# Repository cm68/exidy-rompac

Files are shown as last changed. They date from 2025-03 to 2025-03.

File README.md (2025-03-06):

this is a 3d printable exidy rom-pac case, tested with the original rom-pac
and the modern clone at https://github.com/abzman/Exidy-Sorcerer-Stuff

I uploaded it to thingyverse.

install openscad, run make, and print the generated STL files to your
heart's content.

the rompac.stl file is not really useful as anything other than a visual
fit check or thumbnail.

I printed mine on a flashforge guider 2S with PLA, but be fine with anything

PLA at 215 degrees filament, 70 degree platform 
with raft, 25% fill. the pin is a bit weak

PETG at 240, platform 70 with shell thickness = 4mm.  
this has the pin strong enough.

the shells are held together with the press-fit pin, this might want a little
sanding, depending on your printer.  if it is loose, tape works.
i might put locking tabs on the inside surfaces of the front bevel,
if you do this before me, send it to me at curt@zen-room.org.

yeah, it's GPL3.  ship it and derived works with buildable source code; 
if you learned something from this, you must pay that learning forward.

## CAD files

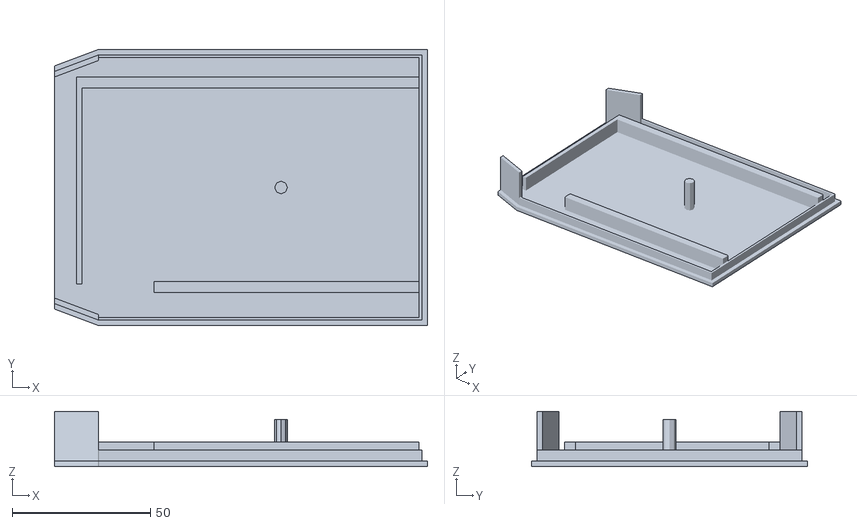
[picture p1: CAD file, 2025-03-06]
rompac-t.stl
135.0 x 100.0 x 20.0

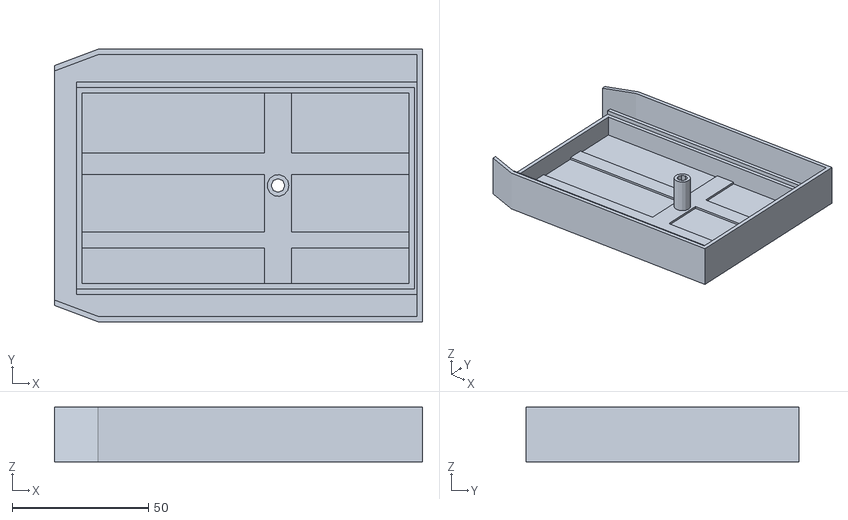
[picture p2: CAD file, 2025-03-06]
rompac-b.stl
135.0 x 100.0 x 20.0

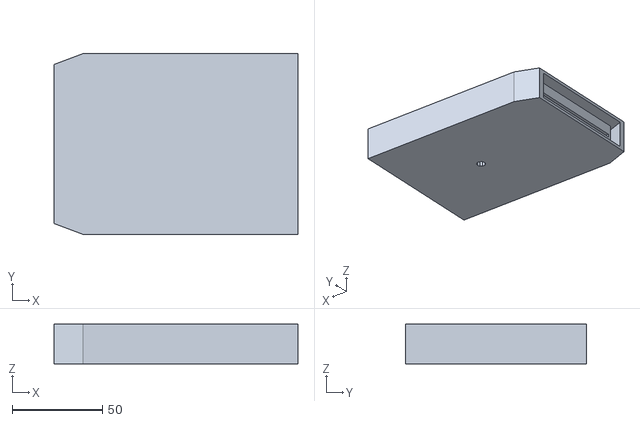
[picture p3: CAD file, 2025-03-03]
rompac.stl
135.0 x 100.0 x 22.0

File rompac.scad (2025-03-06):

/*
 * $Id: rompac.scad 2029 2025-03-02 08:44:02 curt
 */

width = 100;
length = 135;
basethick = 2;
pin = 82;
bevel_width = 6;
bevel_len = 16;
high = 20;
plat = 11;
sidethick = 2;

/* size of pin and hole */
pinouter = 4; // fixed by size of PCB hole
pininner = 2.3;
pinhole = 2.5;
pinlength = high - 3;

// edit this to generate either "b" - bottom
// or "t" - top
// or both -"tb"
express = "tb";

module platform() {
    translate([8,12,0]) cube([2,73,plat]);
    translate([8,12,0]) cube([124,2,plat]);
    translate([8,84,0]) cube([124,2,plat]);
    translate([130,12,0]) cube([2,73,plat]); 
}

module lip() {
    translate([8,10,0]) cube([126,2,plat+2]);
    translate([8,86,0]) cube([126,2,plat+2]);
    translate([132,10,0]) cube([2,78,plat+2]); 
}

module base() {
    difference() {
        linear_extrude(height = basethick) 
            polygon([
                [ 0, bevel_width],
                [ 0, width - bevel_width],
                [ bevel_len, width],
                [ length, width],
                [ length, 0],
                [ bevel_len, 0]]);
        translate([10, 14, 1]) cube([120, 70, 2]);
    }
    translate([0, 54, 0]) cube([length, 8, 2]);
    translate([0, 27, 0]) cube([length, 6, 2]);
    translate([pin - 5, 0, 0]) cube([10, width, 2]);
}

module edge() {
    union() {
        translate([bevel_len, 0, 0]) cube([length - bevel_len, sidethick, high]);
        translate([length - sidethick, 0, 0]) cube([sidethick, width, high]);
        translate([bevel_len, width - sidethick, 0]) cube([length - bevel_len, sidethick, high]);
        linear_extrude(height = high) union() {
            polygon([[0, bevel_width + sidethick], [0, bevel_width], 
                [bevel_len, 0], [bevel_len, sidethick]]);
            polygon([[0, width - bevel_width], [0, width - bevel_width - sidethick], 
                [bevel_len, width - sidethick], [bevel_len, width]]);
        }
    }
}

module top() {
    toplip = 6;
    linear_extrude(height = basethick) 
        polygon([
                [ 0, bevel_width],
                [ 0, width - bevel_width],
                [ bevel_len, width],
                [ length, width],
                [ length, 0],
                [ bevel_len, 0]]);
    
    translate([pin, width / 2, 0]) cylinder(pinlength, r = pininner);

    translate([bevel_len, sidethick, 0]) cube([length - bevel_len - sidethick, 1, toplip]);
    translate([length - sidethick - 1, sidethick, 0]) cube([1, width - (sidethick * 2), toplip]);
    translate([bevel_len, width - sidethick - 1, 0]) cube([length - bevel_len - sidethick, 1, toplip]);
    linear_extrude(height = 20) {
        polygon([[0, bevel_width + (sidethick *2)], [0, bevel_width + sidethick], 
                [bevel_len, sidethick], [bevel_len, (sidethick*2)]]);
        polygon([[0, width - bevel_width - sidethick], [0, width - bevel_width - (sidethick * 2)], 
                [bevel_len, width - (sidethick * 2)], [bevel_len, width-sidethick]]);
    }
    translate([8,15,0]) cube([2,72, high - plat]);
    translate([36, 12, 0]) cube([96,4, high - plat]);
    translate([8, 86, 0]) cube([124,4, high - plat]);
}

if (search("b", express)) {
    difference() {
        union() {
            edge();
            base();
            translate([pin, width / 2, 0]) cylinder(high-2, r = pinouter);
            platform();
        }
        translate([pin, width / 2, -1]) cylinder(high+2, r = pinhole);
    }
    color("blue") lip();
}

if (search("t", express)) {
    echo("t");
    if (search("b", express)) {
        color("red") translate([0, width, high+2]) rotate([180, 0, 0]) top();
        echo("tb");
    } else {
        top();
    }
}

 

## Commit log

2025-02-27 checkin for first ok prototype
    [rompac-b.stl, rompac-t.stl, rompac.scad]
2025-02-27 better README, added composite view
    [rompac.stl]
2025-03-01 better fit, clamp
    [rompac-b.stl, rompac-t.stl, rompac.scad]
2025-03-02 more base reinforcement, cutout for jumpers
    [rompac-b.stl, rompac-t.stl, rompac.scad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]
2025-03-02 top hole, squire
    [rompac-b.stl, rompac.scad, rompac.stl]
2025-03-03 bigger pin
    [rompac-b.stl, rompac-t.stl, rompac.scad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]
2025-03-03 parameterise pin
    [rompac-b.stl, rompac-t.stl, rompac.scad]
2025-03-06 PETG details, pin tweaks
    [rompac-b.stl, rompac-t.stl, rompac.scad]
